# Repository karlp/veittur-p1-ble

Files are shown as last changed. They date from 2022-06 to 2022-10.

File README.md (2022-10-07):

## P1 HAN port to BLE

Nothing fancy, a euro HAN P1 port from an electricity meter to BLE.
Includes a ws2812 style LED for local indication, and a header for debug and programming.
Nothing else at all really, total BOM is ~$2.  You'll need to add your own RJ12/6P6C cable,
and have BLE range.

intention is to re-use something that already exists in homeassistant protocol wise...

## Sample
### 2022-10 revision
Adds USB, parts replaced to match JLCPCB production.
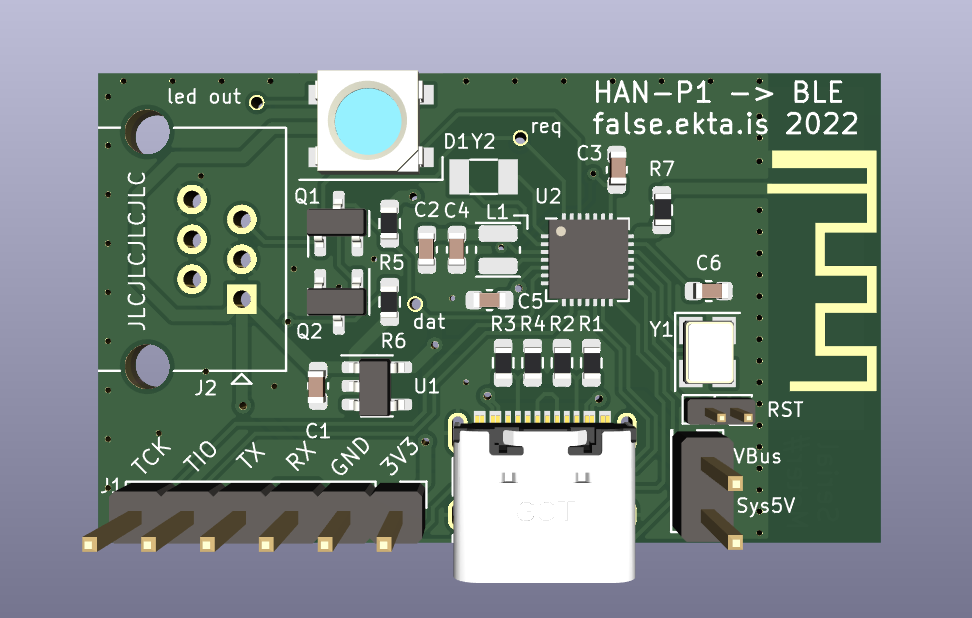
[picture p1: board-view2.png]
board-view


### Initial revision (conflicting pin definitions, overly simplistic)
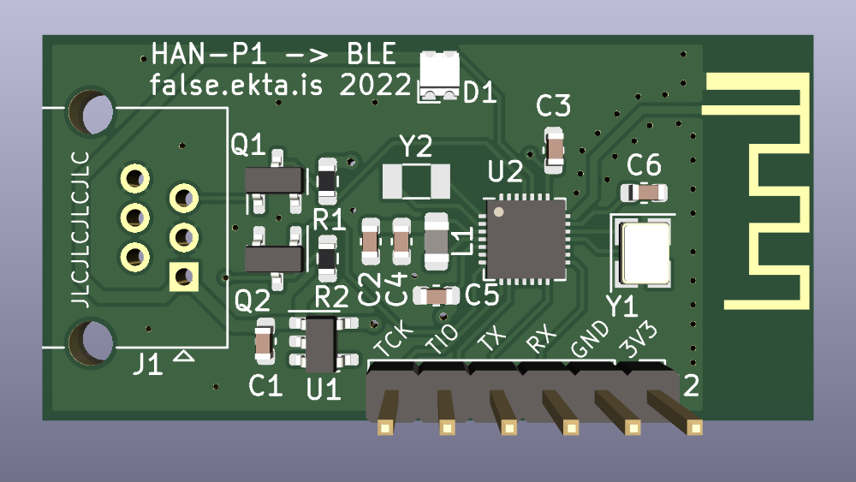
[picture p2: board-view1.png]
board-view


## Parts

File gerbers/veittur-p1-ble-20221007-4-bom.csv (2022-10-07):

Comment | Designator | Footprint | JLCPCB Part #
WS2812B-V5/W | D1 | LED_WS2812B_PLCC4_5.0x5.0mm_P3.2mm | C2874885
10uH | L1 | L_Changjiang_FNR252012S | C37428
BSS138 | Q1,Q2 | SOT-23 | C406812
MIC5504-3.3YM5 | U1 | SOT-23-5 | C347386
2.2uF | C2,C6,C5,C1,C3 | C_0603_1608Metric | C23630
32M | Y1 | Crystal_SMD_3225-4Pin_3.2x2.5mm | C337683
10k | R3,R1,R4,R6,R2,R5 | R_0603_1608Metric | C25804
0 | R7 | R_0603_1608Metric | C21189
CH582F | U2 | QFN-28-1EP_4x4mm_P0.4mm_EP2.6x2.6mm | C3001175
32k | Y2 | Crystal_SMD_3215-2Pin_3.2x1.5mm | C271654
USB_C_Receptacle_USB2.0 | J1 | USB_C_Receptacle_XKB_U262-16XN-4BVC11 | C319148
100nF | C4 | C_0603_1608Metric | C14663

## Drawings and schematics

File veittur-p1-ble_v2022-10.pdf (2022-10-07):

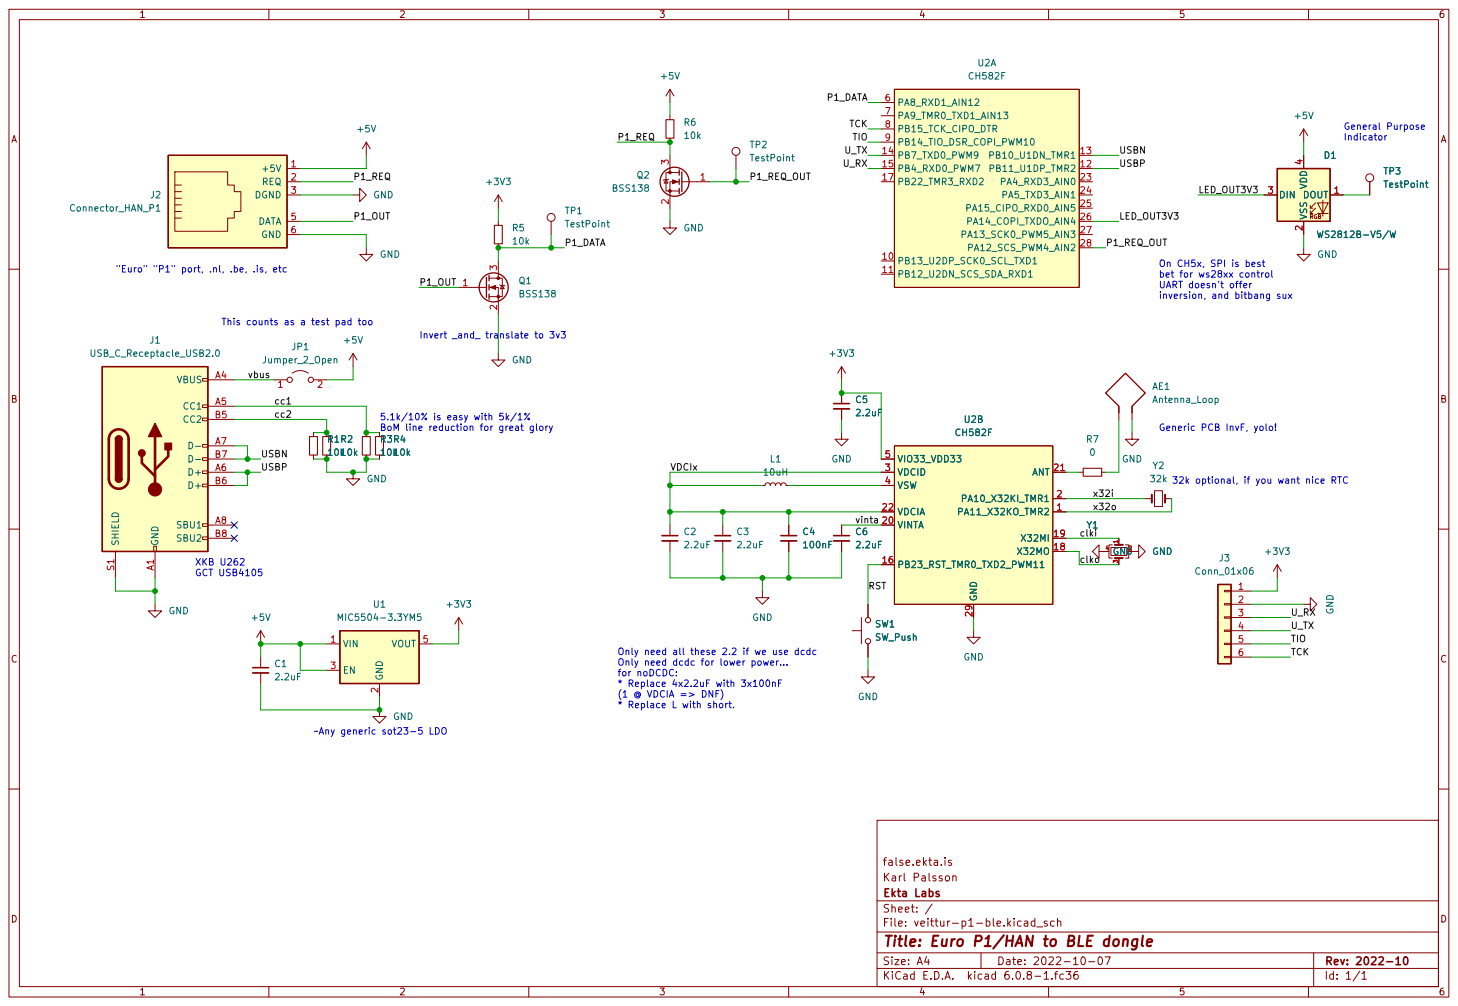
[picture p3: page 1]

Indicator Only need all these 2.2 if we use dcdc

inversion, and bitbang sux

5.1k/10% is easy with 5k/1%
BoM line reduction for great glory

Generic PCB InvF, yolo!

32k optional, if you want nice RTC

Only need dcdc for lower power...
for noDCDC: * Replace 4x2.2uF with 3x100nF

File: veittur-p1-ble.kicad_sch Sheet: / Ekta Labs Karl Palsson

Id: 1/1 Title: Euro P1/HAN to BLE dongle

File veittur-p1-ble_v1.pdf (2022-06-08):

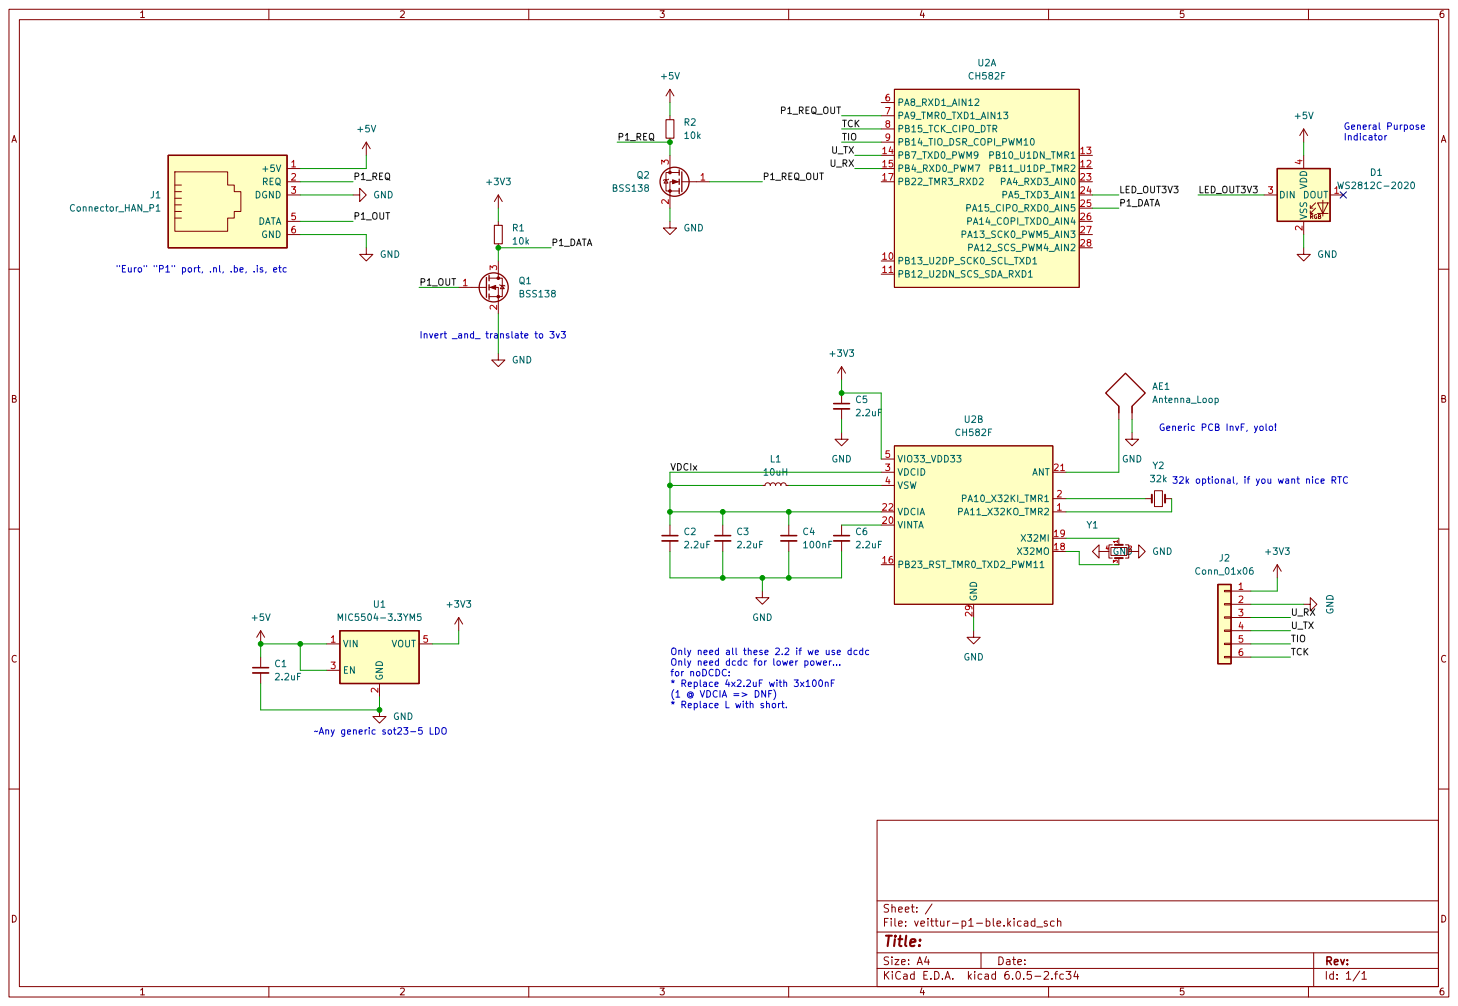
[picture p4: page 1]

Indicator "Euro" "P1" port, .nl, .be, .is, etc

Generic PCB InvF, yolo!

32k optional, if you want nice RTC

Only need dcdc for lower power...
for noDCDC: * Replace 4x2.2uF with 3x100nF

File: veittur-p1-ble.kicad_sch Sheet: /
Id: 1/1 Title:

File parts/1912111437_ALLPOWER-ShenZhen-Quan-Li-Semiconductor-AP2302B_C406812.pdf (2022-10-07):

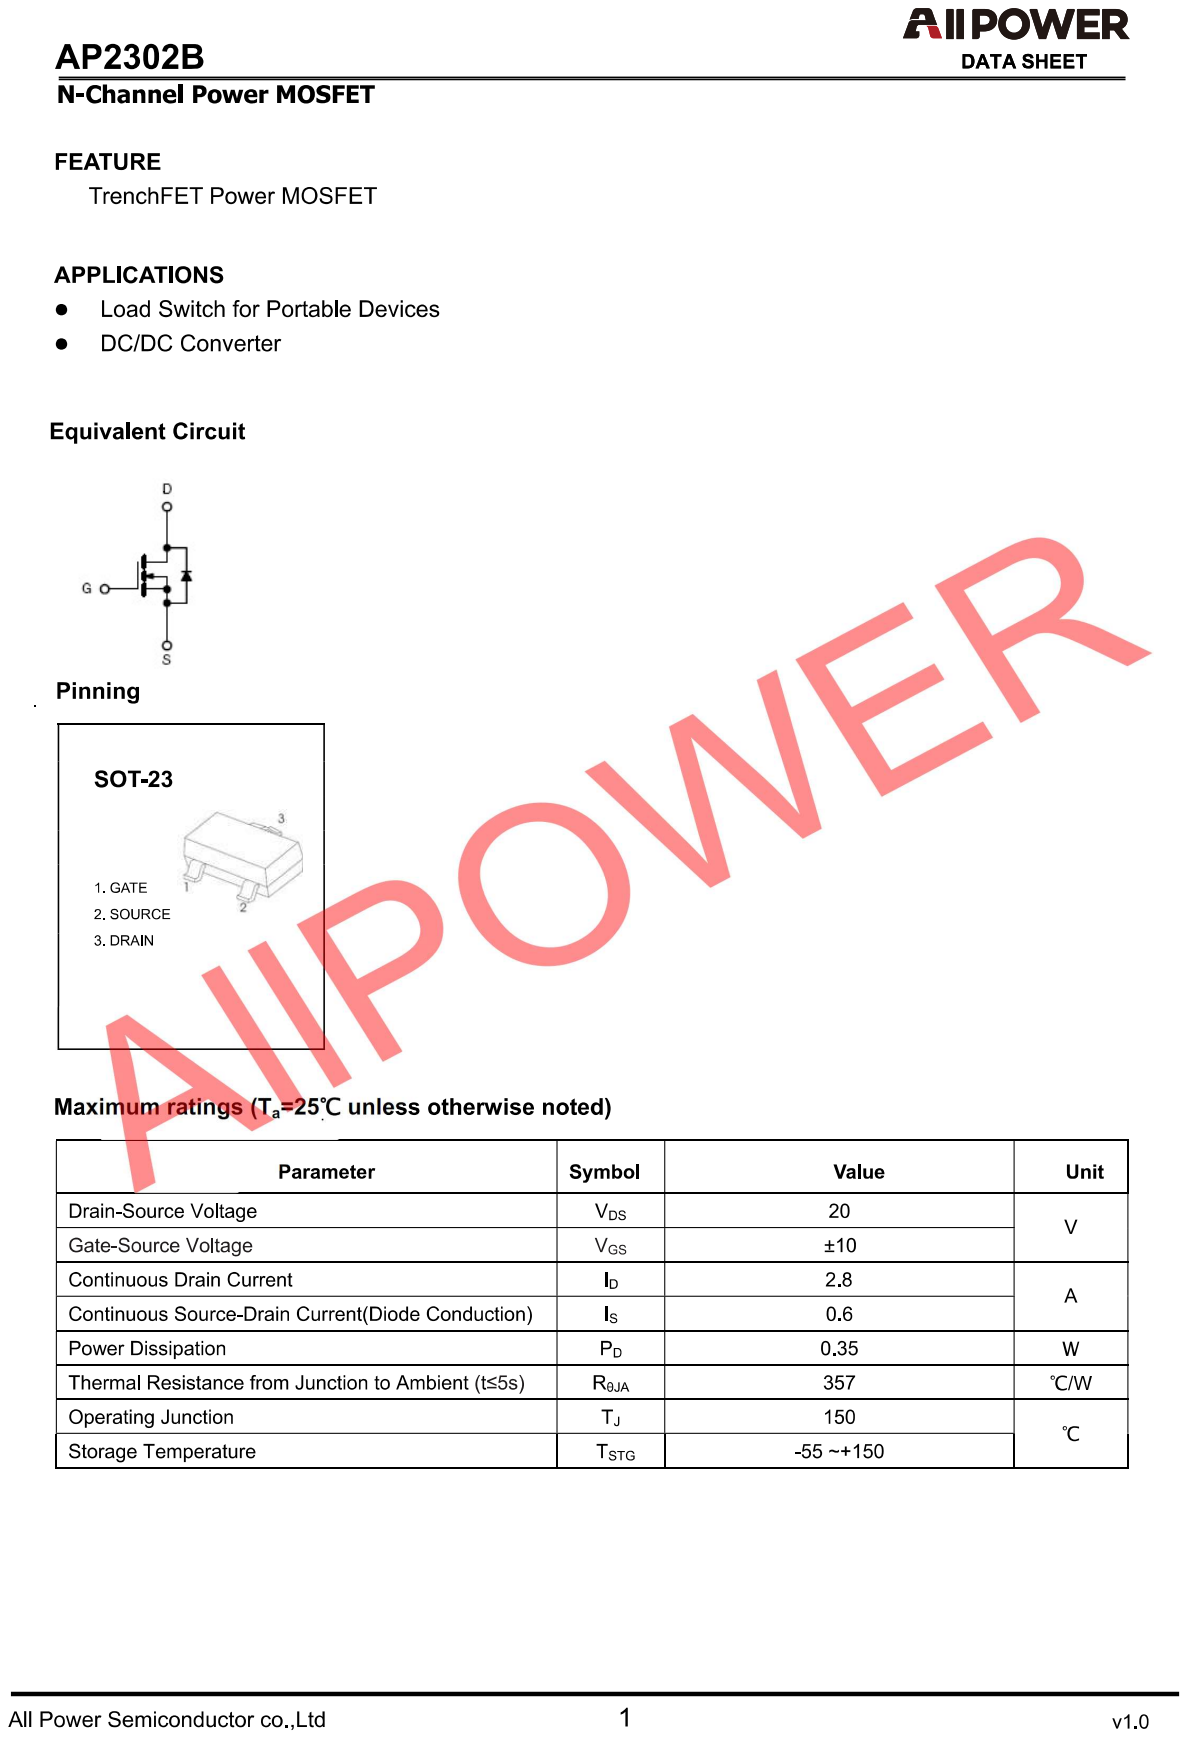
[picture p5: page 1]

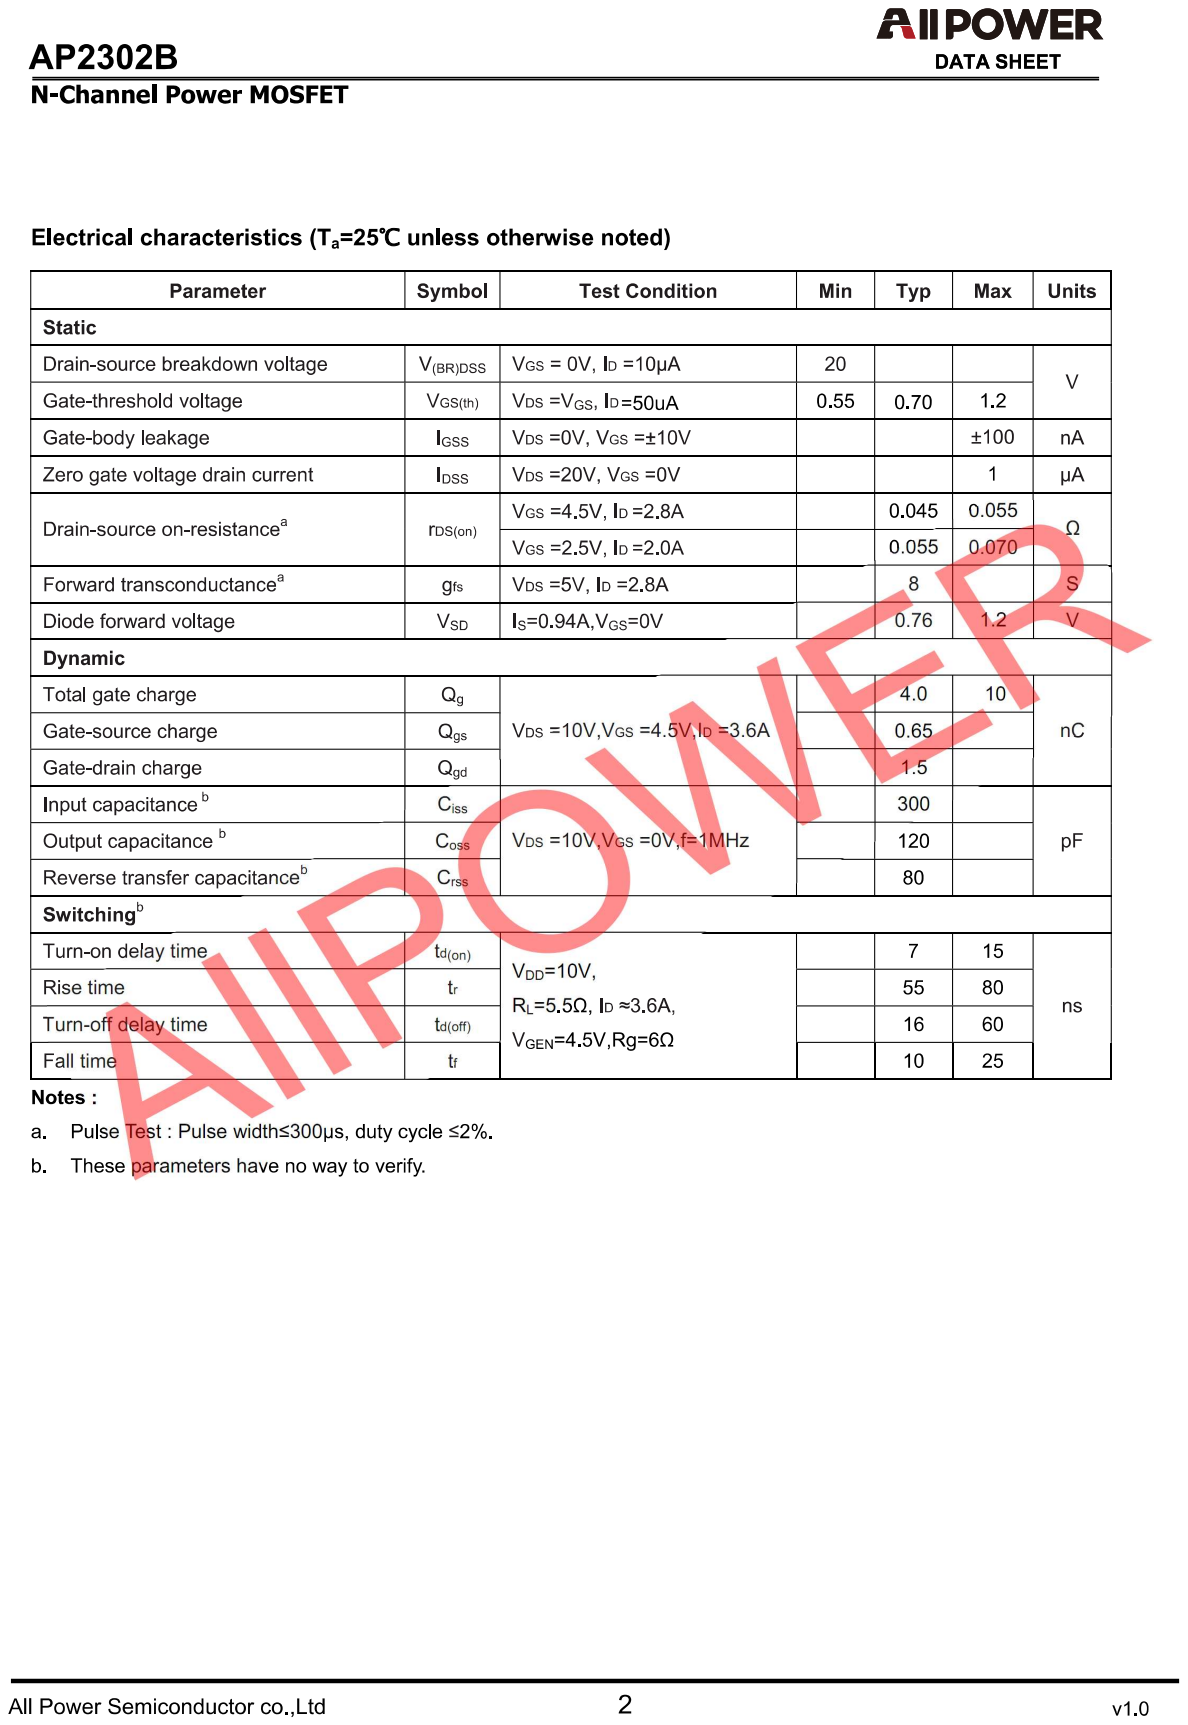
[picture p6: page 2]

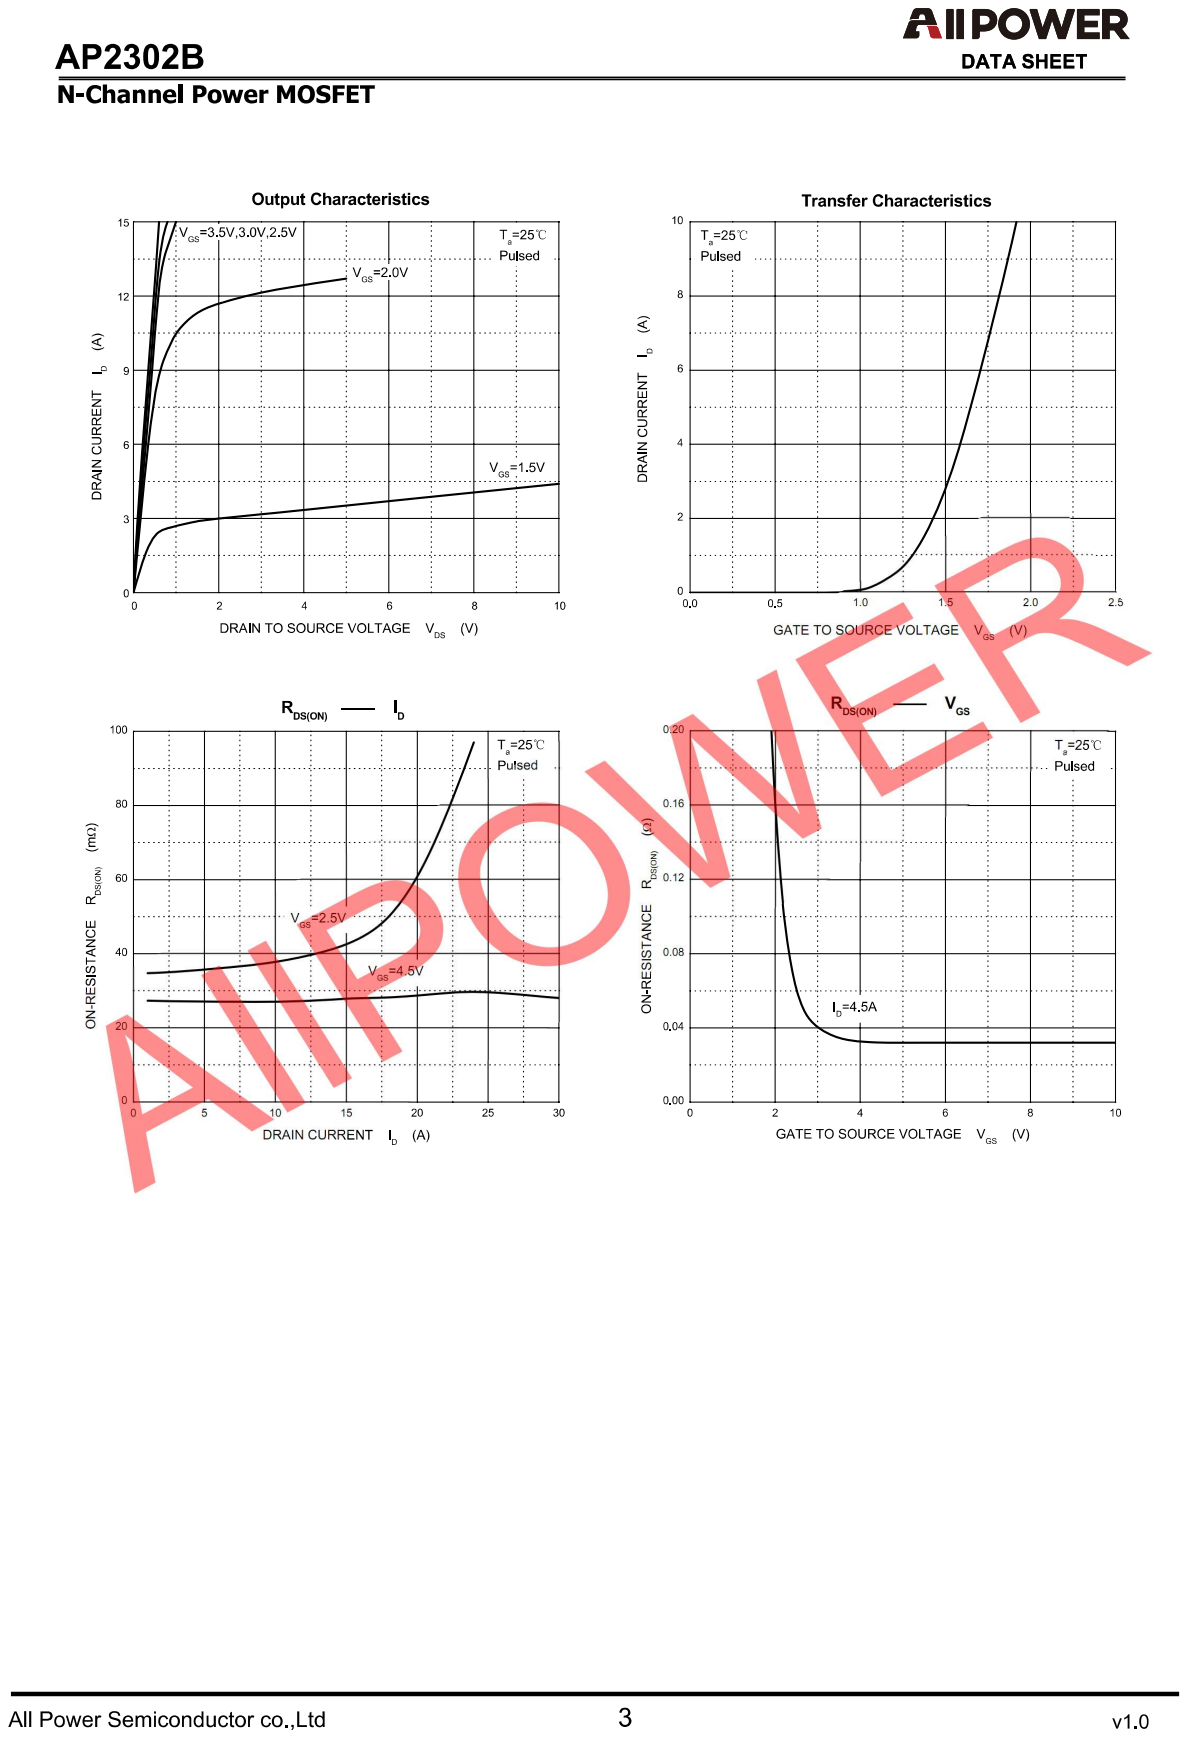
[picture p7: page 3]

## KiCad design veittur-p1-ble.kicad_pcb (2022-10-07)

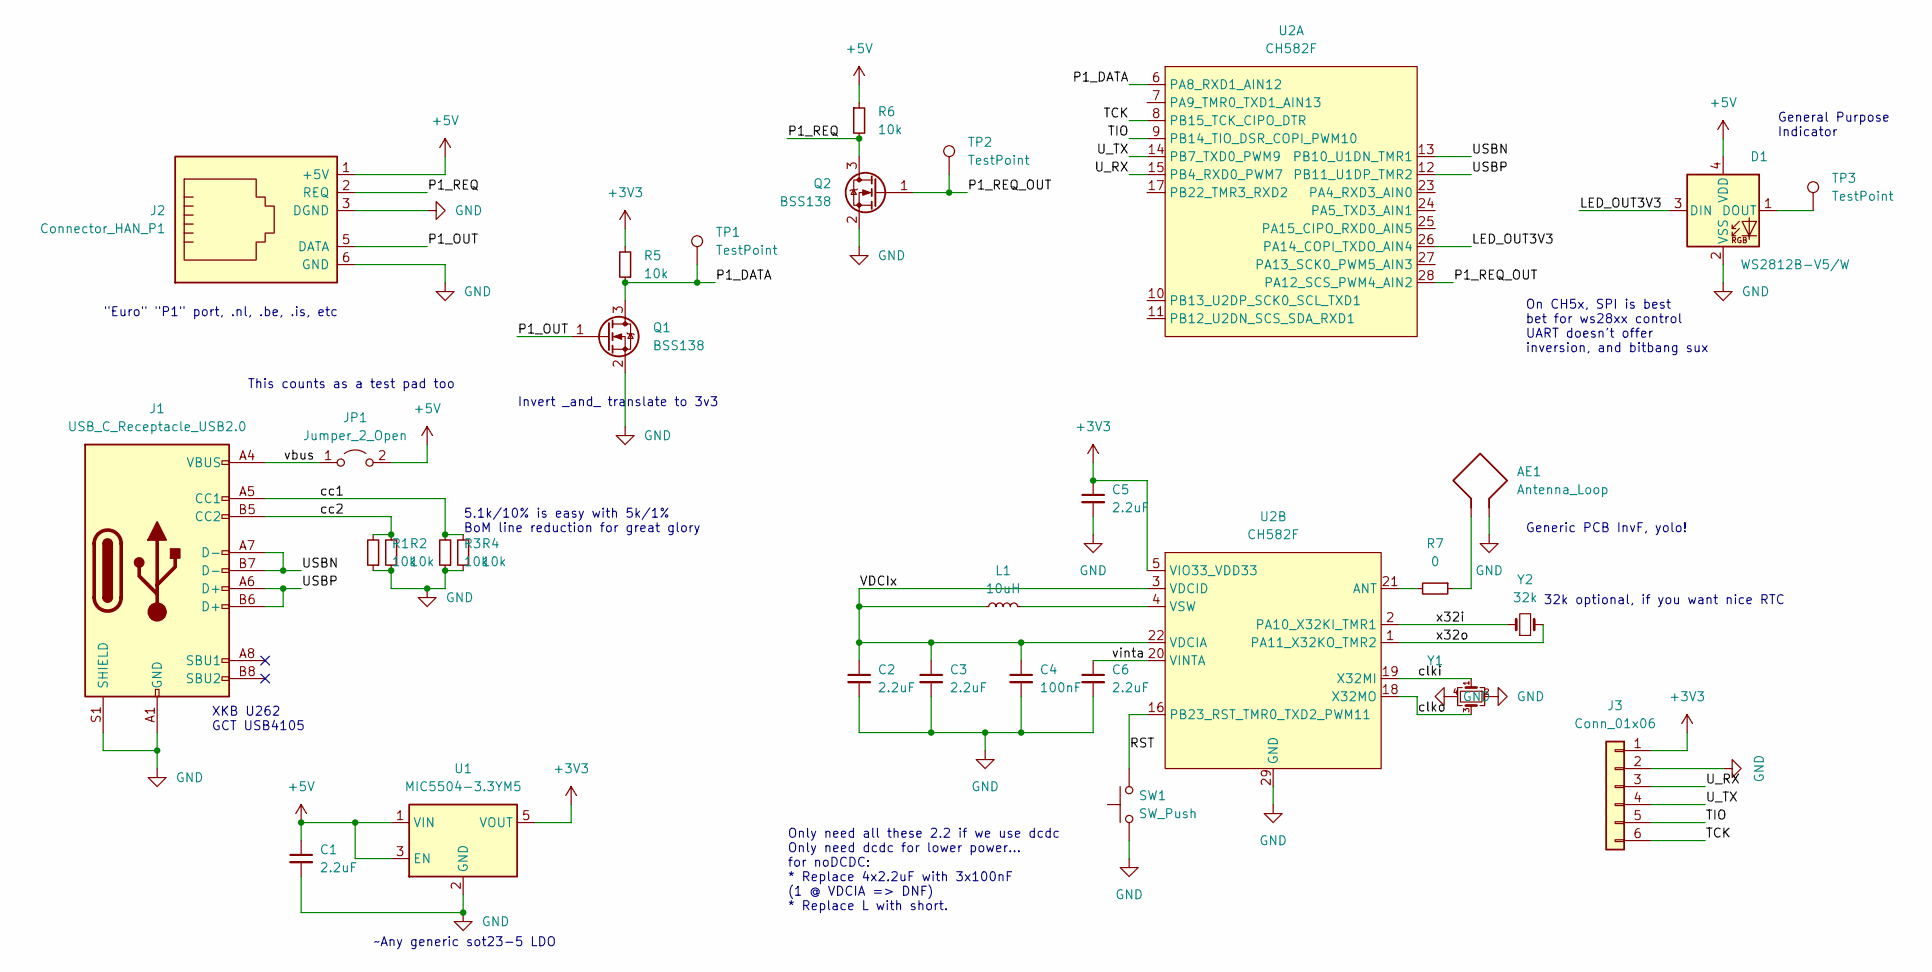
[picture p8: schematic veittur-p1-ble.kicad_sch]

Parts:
AE1: Antenna_Loop; ANT-F-1-2.4G-1.6MM-FR4-WCH-FLIP
C1, C2, C3, C5, C6: 2.2uF; C_0603_1608Metric; MPN CL10A225KO8NNNC; lcsc# C23630
C4: 100nF; C_0603_1608Metric; MPN CC0603KRX7R9BB104; lcsc# C14663
D1: WS2812B-V5/W; LED_WS2812B_PLCC4_5.0x5.0mm_P3.2mm; MPN WS2812B-V5/W; lcsc# C2874885
J1: USB_C_Receptacle_USB2.0; USB_C_Receptacle_XKB_U262-16XN-4BVC11; MPN U262-161N-4BVC11; lcsc# C319148
J2: Connector_HAN_P1; RJ25_Wayconn_MJEA-660X1_Horizontal; MPN R-RJ11R06P-A801
J3: Conn_01x06; PinHeader_1x06_P2.54mm_Vertical
JP1: Jumper_2_Open; PinHeader_2x01_P2.54mm_Vertical
L1: 10uH; L_Changjiang_FNR252012S; MPN SWPA252012S100MT; lcsc# C37428
Q1, Q2: BSS138; SOT-23; MPN AP2302B; lcsc# C406812
R1, R2, R3, R4, R5, R6: 10k; R_0603_1608Metric; MPN 0603WAF1002T5E; lcsc# C25804
R7: 0; R_0603_1608Metric; MPN 0603WAF0000T5E; lcsc# C21189
SW1: SW_Push; PinHeader_2x01_P1.27mm_Vertical
TP1, TP2, TP3: TestPoint; TestPoint_Plated_Hole_0.6_D0.8mm
U1: MIC5504-3.3YM5; SOT-23-5; MPN XC6219B332MR; lcsc# C347386
U2: CH582F; QFN-28-1EP_4x4mm_P0.4mm_EP2.6x2.6mm; MPN CH582F; lcsc# C3001175
Y1: 32M; Crystal_SMD_3225-4Pin_3.2x2.5mm; MPN X322532MMB4SI; lcsc# C337683
Y2: 32k; Crystal_SMD_3215-2Pin_3.2x1.5mm; MPN Q13FC1350000400; lcsc# C271654

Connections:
+3V3: C5.1, J3.1, R5.2, U1.5 (VOUT), U2.5 (VIO33_VDD33)
+5V: C1.1, D1.4 (VDD), J2.1 (+5V), JP1.2 (B), R6.1, U1.1 (VIN), U1.3 (EN)
/LED_OUT3V3: D1.3 (DIN), U2.26 (PA14_COPI_TXDO_AIN4)
/P1_DATA: Q1.3 (D), R5.1, TP1.1, U2.6 (PA8_RXD1_AIN12)
/P1_OUT: J2.5 (DATA), Q1.1 (G)
/P1_REQ: J2.2 (REQ), Q2.3 (D), R6.2
/P1_REQ_OUT: Q2.1 (G), TP2.1, U2.28 (PA12_SCS_PWM4_AIN2)
/RST: SW1.2, U2.16 (PB23_RST_TMR0_TXD2_PWM11)
/TCK: J3.6, U2.8 (PB15_TCK_CIPO_DTR)
/TIO: J3.5, U2.9 (PB14_TIO_DSR_COPI_PWM10)
/USBN: J1.A7 (D-), J1.B7 (D-), U2.13 (PB10_U1DN_TMR1)
/USBP: J1.A6 (D+), J1.B6 (D+), U2.12 (PB11_U1DP_TMR2)
/U_RX: J3.3, U2.15 (PB4_RXD0_PWM7)
/U_TX: J3.4, U2.14 (PB7_TXD0_PWM9)
/VDCIx: C2.1, C3.1, C4.1, L1.1, U2.3 (VDCID), U2.22 (VDCIA)
/cc1: J1.A5 (CC1), R3.2, R4.2
/cc2: J1.B5 (CC2), R1.2, R2.2
/clki: U2.19 (X32MI), Y1.1
/clko: U2.18 (X32MO), Y1.3
/vbus: J1.A4 (VBUS), J1.A9 (VBUS), J1.B4 (VBUS), J1.B9 (VBUS), JP1.1 (A)
/vinta: C6.1, U2.20 (VINTA)
/x32i: U2.2 (PA10_X32KI_TMR1), Y2.1
/x32o: U2.1 (PA11_X32KO_TMR2), Y2.2
GND: AE1.2, C1.2, C2.2, C3.2, C4.2, C5.2, C6.2, D1.2 (VSS), J1.A1 (GND), J1.A12 (GND), J1.B1 (GND), J1.B12 (GND), J1.S1 (SHIELD), J2.3 (DGND), J2.6 (GND), J3.2, Q1.2 (S), Q2.2 (S), R1.1, R2.1, R3.1, R4.1, SW1.1, U1.2 (GND), U2.29 (GND), Y1.2, Y1.4
unnamed: AE1.1, R7.1
unnamed: D1.1 (DOUT), TP3.1
unnamed: L1.2, U2.4 (VSW)
unnamed: R7.2, U2.21 (ANT)

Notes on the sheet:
32k optional, if you want nice RTC
Invert _and_ translate to 3v3
~Any generic sot23-5 LDO
This counts as a test pad too
5.1k/10% is easy with 5k/1% BoM line reduction for great glory
"Euro" "P1" port, .nl, .be, .is, etc
XKB U262 GCT USB4105
General Purpose Indicator
On CH5x, SPI is best bet for ws28xx control UART doesn't offer inversion, and bitbang sux
Only need all these 2.2 if we use dcdc Only need dcdc for lower power... for noDCDC: * Replace 4x2.2uF with 3x100nF (1 @ VDCIA => DNF) * Replace L with short.
Generic PCB InvF, yolo!

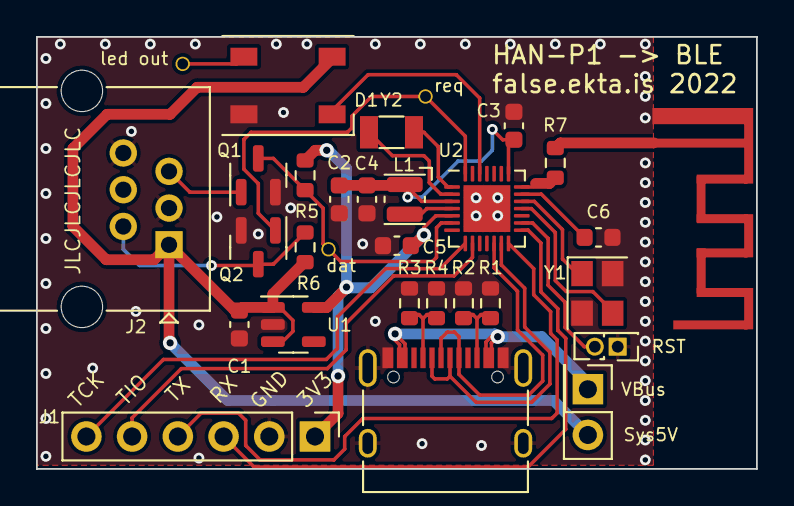
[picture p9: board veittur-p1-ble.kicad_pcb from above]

Board: 2 copper layers, 40.0 x 24.0 mm, 30 parts (0 on the bottom side), 28 nets.

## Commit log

2022-06-08 initial commit
    Antenna gnd return insn't connecting properly? what?
    [veittur-p1-ble.kicad_pcb, veittur-p1-ble.kicad_sch]
2022-06-08 initial "complete"
    is that it? should I just order this then?
    [veittur-p1-ble.kicad_pcb, veittur-p1-ble.kicad_sch]
2022-06-08 sample view
2022-06-08 add production gerbers
    [veittur-p1-ble.kicad_pcb]
2022-09-06 add fixit notes for future revs
    [veittur-p1-ble.kicad_sch]
2022-09-06 sch: "fix" "most" fixmes...
    needs review and footprint assignments
    [veittur-p1-ble.kicad_sch]
2022-10-07 overhaul for jlc assembly
    parts changes, revised layout, added the usb connector, just for fun...
    [veittur-p1-ble.kicad_pcb, veittur-p1-ble.kicad_sch]
2022-10-07 finalize production for rev2.
    parts all adjusted for JLCPCB, bom and position files all uploaded
    happily.
    [veittur-p1-ble-20221007-4-bom.csv, veittur-p1-ble.kicad_pcb, veittur-p1-ble.kicad_sch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]
2022-10-07 new board view image
2022-10-07 Generate new pdfs and set page settings
    [veittur-p1-ble.kicad_sch]
